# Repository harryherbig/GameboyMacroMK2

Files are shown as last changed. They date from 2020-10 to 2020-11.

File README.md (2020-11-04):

# Game Boy Macro - MK2
My MK2 version of a Gameboy Macro body / faceplate. 

This repo contains:
- STL files for 3D printing
- Fusion 360 f3d file
- printing instructions
- my goals and assembly instructions for additional information

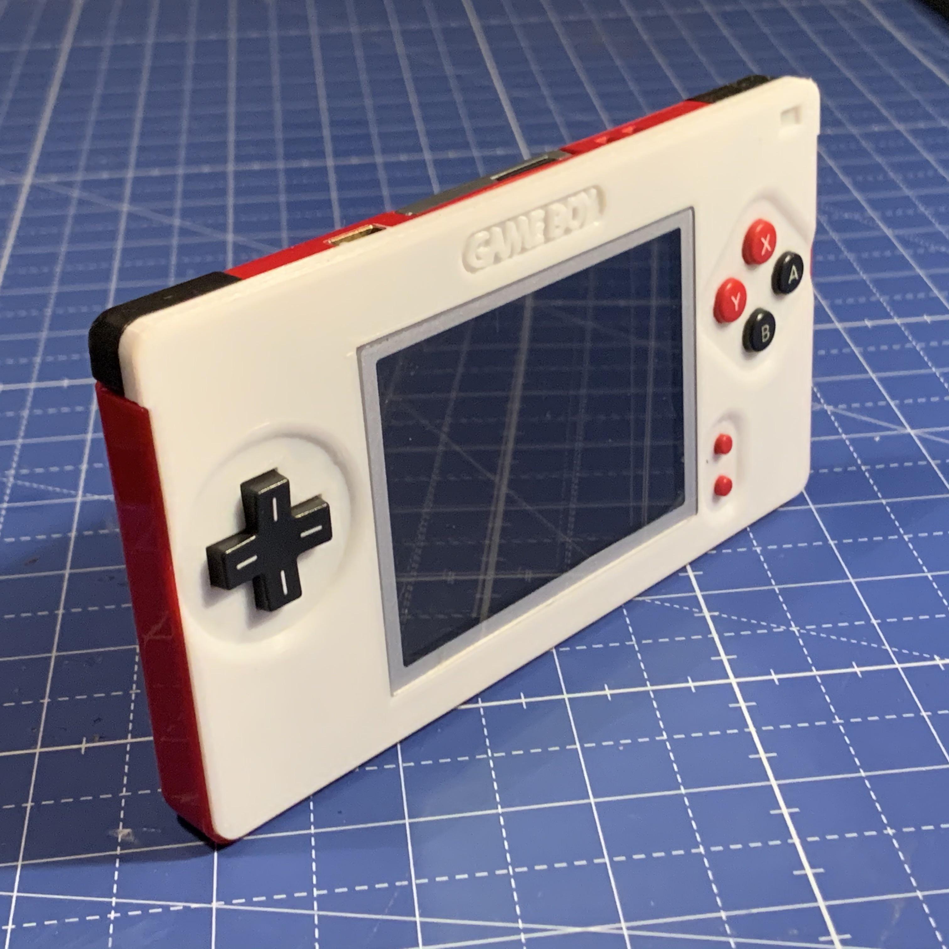
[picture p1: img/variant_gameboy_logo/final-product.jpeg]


This design is based on the upstream of this repository, please also see the original readme:
https://github.com/gb9k/GameboyMacro

Find this design on [https://www.thingiverse.com/thing:4643548](https://www.thingiverse.com/thing:4643548)

## Github Stars
I do projects like this as a hobby in my free time for my own purpose - I have no commercial intentions.
I like the thought of open source, so I decided to not only share the STL files but also the source files for Fusion 360 for you to be able to adapt this to your own needs. 
If you like this project or even use it for your own remix, consider giving this repo a "star" to show your appreciation for my work. 

## buy me a coffee
This project exists only because I had a particular idea that I wanted to realise. Because of the positive feedback I got I decided to open source it, and this is a lot of additional work. 
If you can contribute or you want to, feel free to do it at [Buy me a coffee! ☕](https://buymeacoff.ee/harryurban), I will be really thankfull for anything even if it is a coffee or just a kind comment towards my work, because that helps me a lot.
Be careful and donate just if it is within your possibilities, because there is no refund system.
And remember that you don't need to donate, it is just a free choice for you.
Thank you!

## Photos of printed parts
| part | description | photo |
|---|---|---|
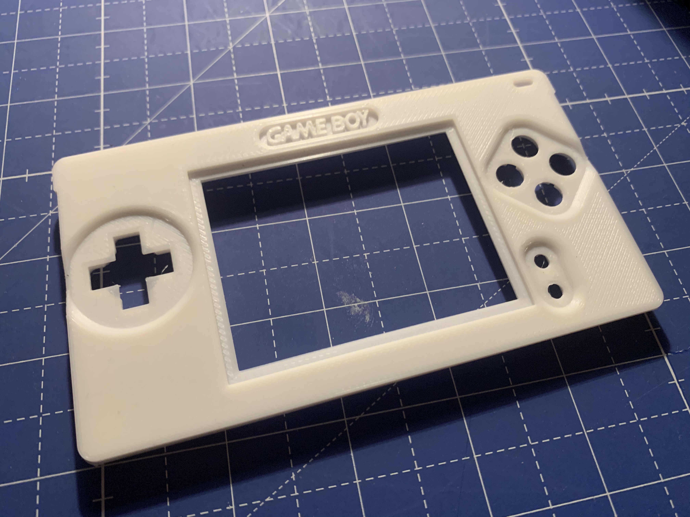
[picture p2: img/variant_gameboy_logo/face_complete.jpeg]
| face+back | glued together |  |
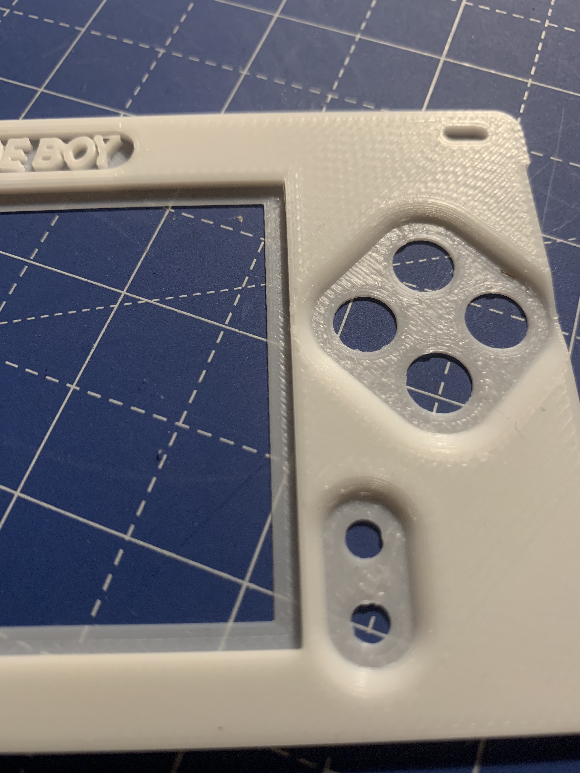
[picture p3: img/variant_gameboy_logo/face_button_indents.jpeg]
| face | indent for ABXY and start/select |  |
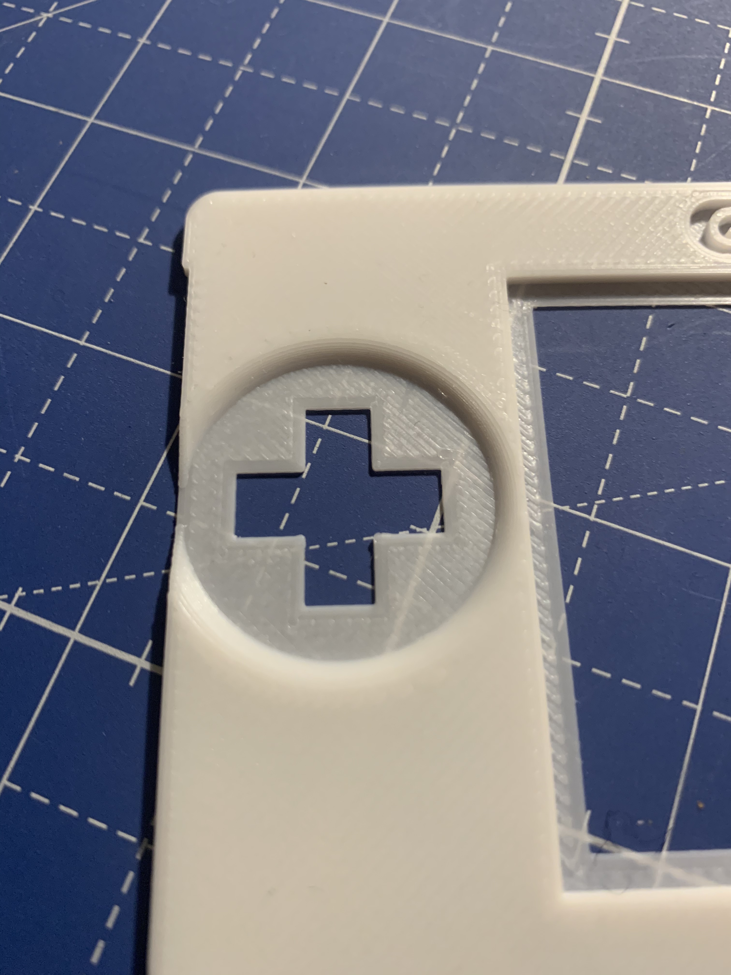
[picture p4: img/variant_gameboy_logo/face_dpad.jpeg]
| face | indent for D-Pad |  |
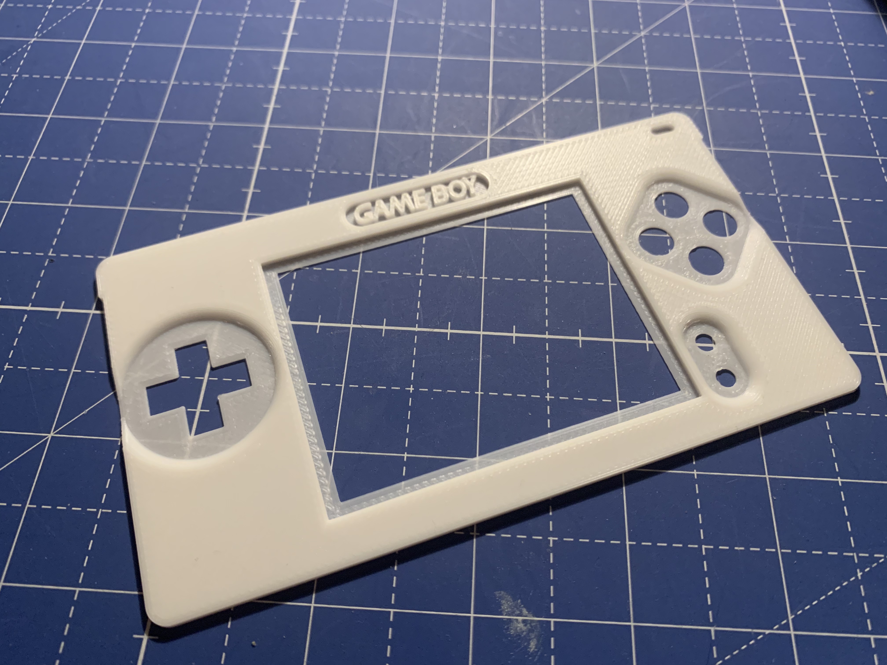
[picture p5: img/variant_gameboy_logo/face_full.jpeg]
| face | full view of the face |  |
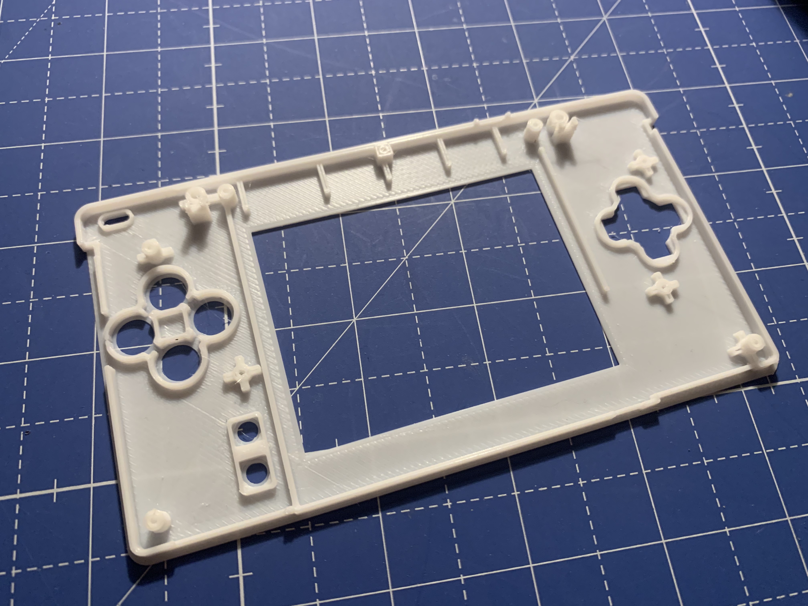
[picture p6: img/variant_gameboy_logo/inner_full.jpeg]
| back | full view of the back |  |
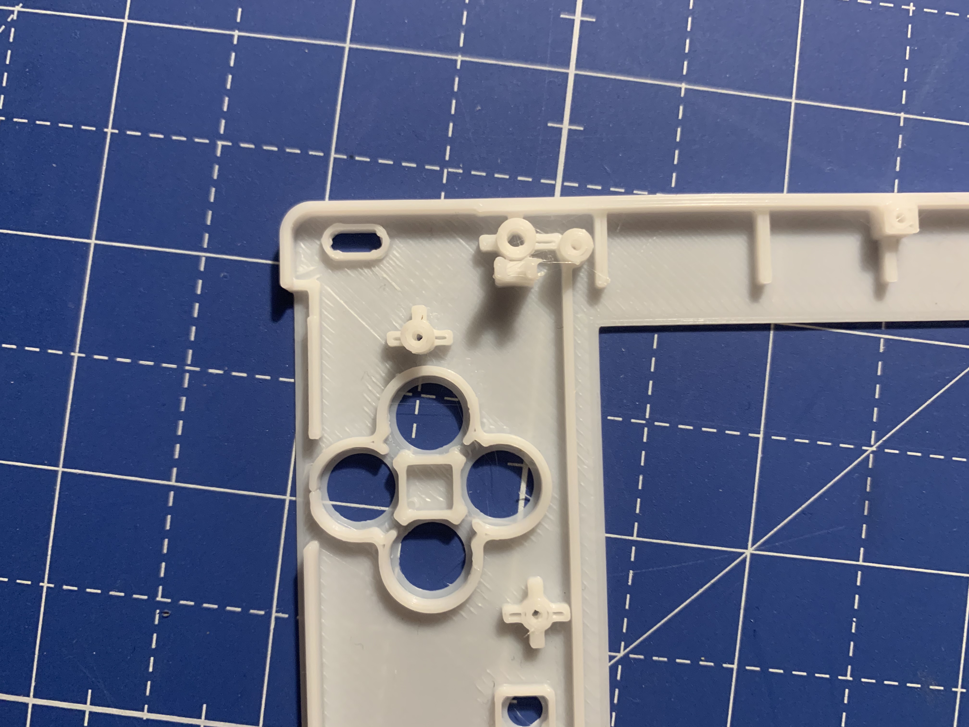
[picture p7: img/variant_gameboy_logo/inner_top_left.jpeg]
| back | led hole and screw hole reinforcements |  |
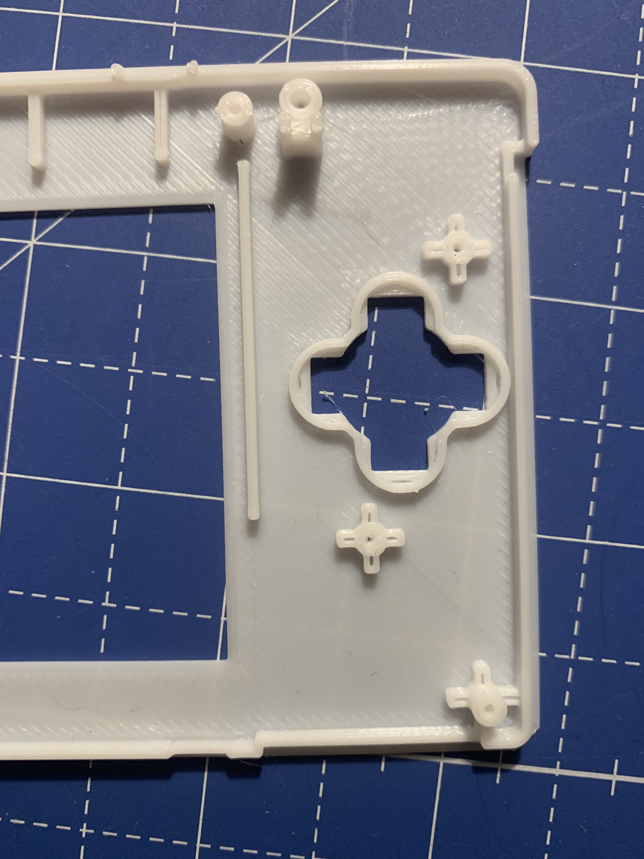
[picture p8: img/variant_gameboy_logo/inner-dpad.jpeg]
| back | inner dpad with reinforcements |  |

## Goals of the design
- Game Boy logo
- smooth transitions from all button indents to the top face (edge fillets)
- a recessed frame using the top screen plastic lense as a cover for the display, because it is unprotected without having the touch screen attached
- Full screen sized cutout in order to accomodate the entire display. (I use it with an R4-sdhc card so I wanted see all of the menus)
- .2 mm / 2 layers at the led "hole" to still see it but not fearing water or debris getting in

## Printing instructions
The body is split in two parts because it would be hard to impossible to get a clean result by using support structures.

### Face part
- print with `.15` or `.1` layer height

### Back part
- `.2` layer height is enough
- `2-3` outlines 
- I think I went with .5 line width, but please check in the slicer preview if all of the important lines are printed only as lines to give good structural support and clean outlines
- get your retraction settings right to avoid stringing and manual cleanup afterswards

### Assembly
- Glue parts together with superglue, or what works best for the material you use
- Get the display cover from the top screen and attach it by putting it in the recessed frame. 
  - It just sticks to the original top housing with rubbery adhesive stripes and can be pushed out carefully. 
  - If done properly you can save and reuse the adhesive stripes or just replace it with double sided tape.
  - You can also order replacement lens covers online in different colors.

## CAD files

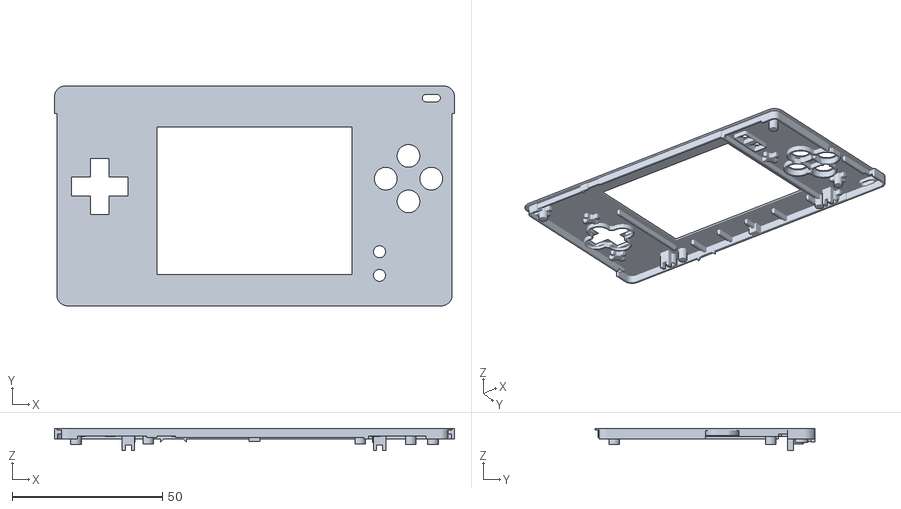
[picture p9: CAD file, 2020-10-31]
4-buttons/Back.stl
133.0 x 73.2 x 7.35

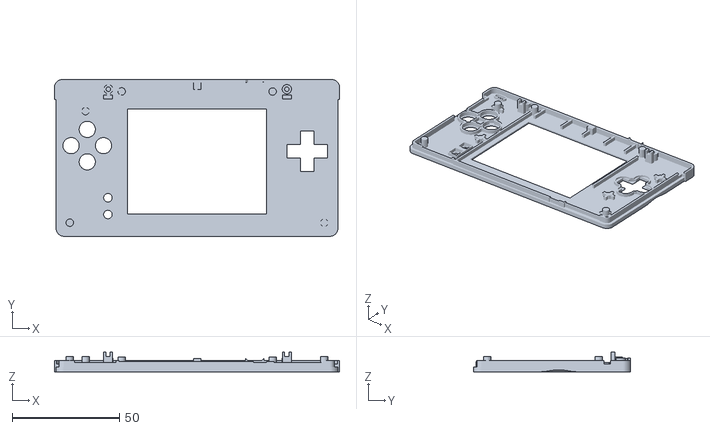
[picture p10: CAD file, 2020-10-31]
4-buttons/variant-gameboy-logo/Combined_Bodies_Gameboy_Logo.stl
133.0 x 73.2 x 9.15

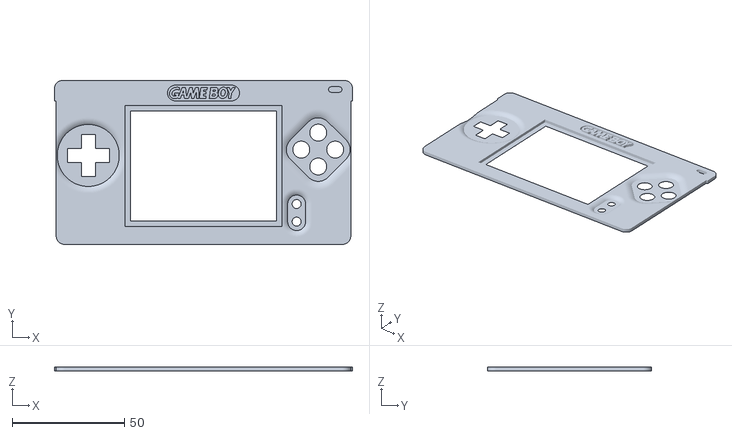
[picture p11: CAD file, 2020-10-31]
4-buttons/variant-gameboy-logo/Faceplate.stl
133.0 x 73.2 x 1.80

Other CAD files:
4-buttons/variant-gameboy-logo/GameboyMacroMK2.f3d

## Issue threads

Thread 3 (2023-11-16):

STLs and Fusion files don't have screw holes

somepin, 2023-11-16:
Had to download and reprint the back STL from [Thingiverse](https://www.thingiverse.com/thing:4643548) to screw the DS lite case into the faceplate.

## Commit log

2020-10-25 changed some dimensions, grouped operations, added indent for display lense, filets around buttons, added crosses around screw towers for better adhesion
    [Faceplate.f3d]
2020-10-31 release of the logo variant
    [Back.stl, Combined_Bodies_Gameboy_Logo.stl, Faceplate.iges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]
2020-11-04 [chore] add assembly instructions
